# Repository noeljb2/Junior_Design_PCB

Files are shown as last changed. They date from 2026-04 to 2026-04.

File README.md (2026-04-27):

# Bop It — Labubu Edition

An ESP32-S3 based interactive reaction-time game ("Bop It" clone) built into a 3D-printed Labubu figure. Players respond to randomized voice prompts by twisting a knob, shaking the figure, or speaking into the microphone. Difficulty ramps with each round, reaction times shorten, and high scores persist across power cycles.

This is the final design archive for a junior-year ECE 1895 project (University of Pittsburgh, Spring 2026).

---

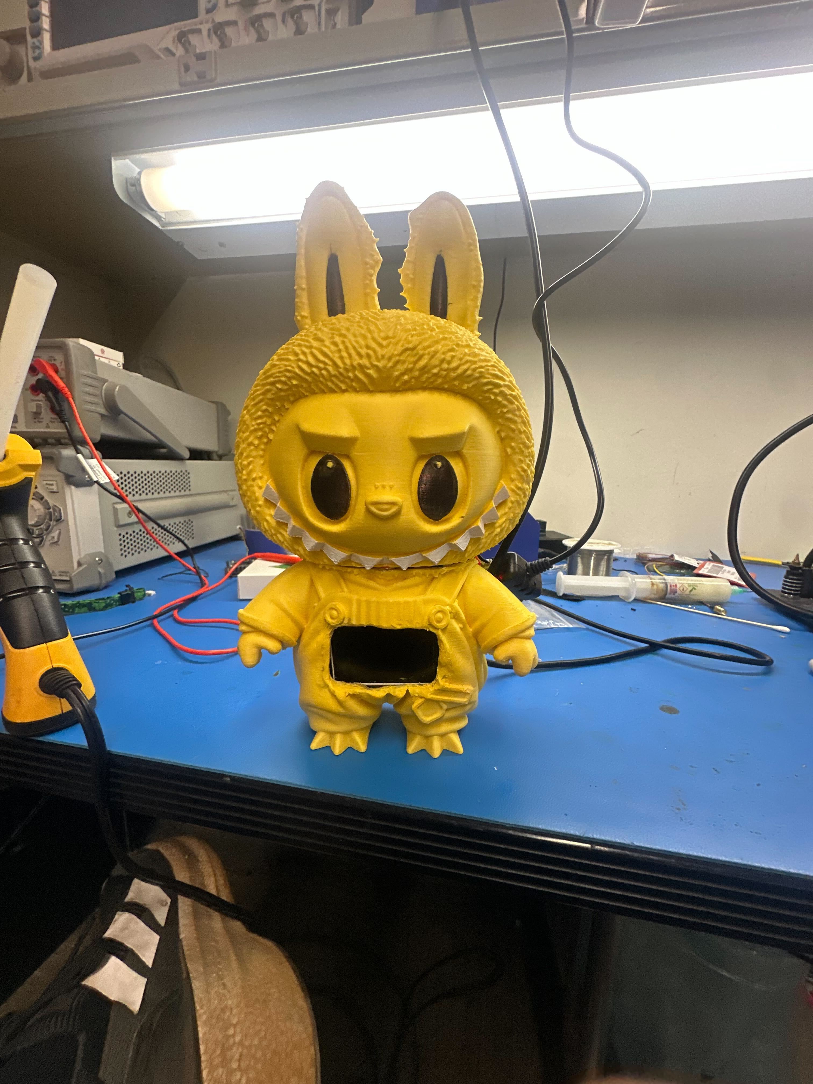
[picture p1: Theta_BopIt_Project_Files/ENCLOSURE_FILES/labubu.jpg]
Front View


## Repository organization

The archive is split by engineering discipline. Each top-level folder is self-contained so that a reviewer (or future builder) can dive into one domain without needing the others.

```
Junior_Design_PCB/
├── README.md                  <- you are here
├── LICENSE
└── Theta_BopIt_Project_Files/
    ├── HARDWARE_DESIGN_FILES/   <- Altium PCB project (schematic, layout, BOM, gerbers, schematic page renders)
    ├── SOFTWARE_FILES/          <- ESP32-S3 firmware (Arduino .ino)
    └── ENCLOSURE_FILES/         <- Bambu Studio 3MF files for 3D-printed parts
```

No external simulation, FEA, or thermal tools were used on this project, so there is no separate `SIMULATION/` folder. Signal-integrity sanity checks were done by hand against the ESP32-S3 datasheet and the peripheral ICs' reference designs.

---

## Hardware

`Theta_BopIt_Project_Files/HARDWARE_DESIGN_FILES/` is an Altium Designer project. The board is a 4-layer PCB built around an ESP32-S3-WROOM-1-N16R8 module.

**Files of interest:**

- `Junior_Design_Bop_It.PrjPcbStructure` — Altium project file. Open this first.
- `LabubuPCB.PcbDoc` — PCB layout (4 layers).
- `MCU.SchDoc` — ESP32-S3 module, decoupling, boot strapping, USB, programming header.
- `USB_POWER.SchDoc` — USB-C input, 5V→3.3V regulation, protection.
- `LCD_AUDIO.SchDoc` — ILI9341 LCD interface and DFPlayer Mini audio interface.
- `Junior_Design_Bop_It.BomDoc` — bill of materials.
- `Gerber_Outputs_Labubu.zip` — fabrication-ready Gerbers (sent to JLCPCB).
- `Junior_Design_Bop_It.PDF` — full printed schematic (all sheets) for review without Altium.

### Schematic

The four sheets of the schematic are rendered below as PNGs so they can be reviewed directly on GitHub without opening the PDF.

**Sheet 1 — MCU + TOP LEVEL**

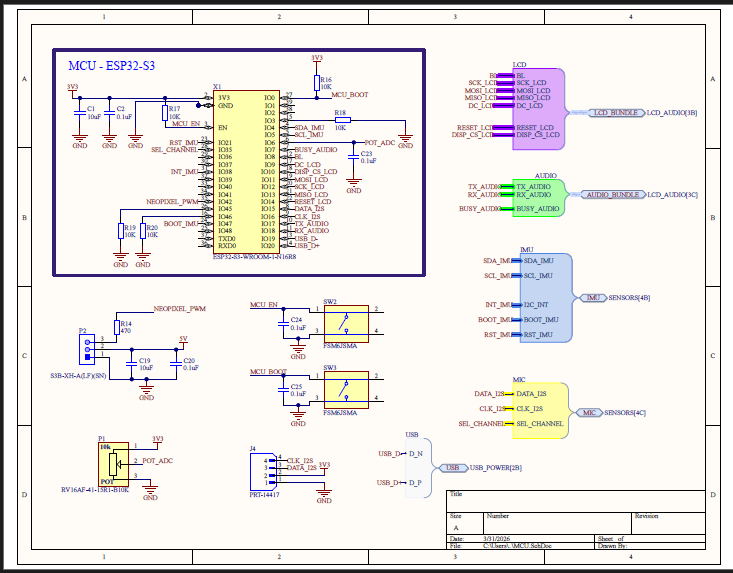
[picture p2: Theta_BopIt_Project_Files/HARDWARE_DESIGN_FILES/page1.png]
Schematic page 1


**Sheet 2 — IMU + MIC**

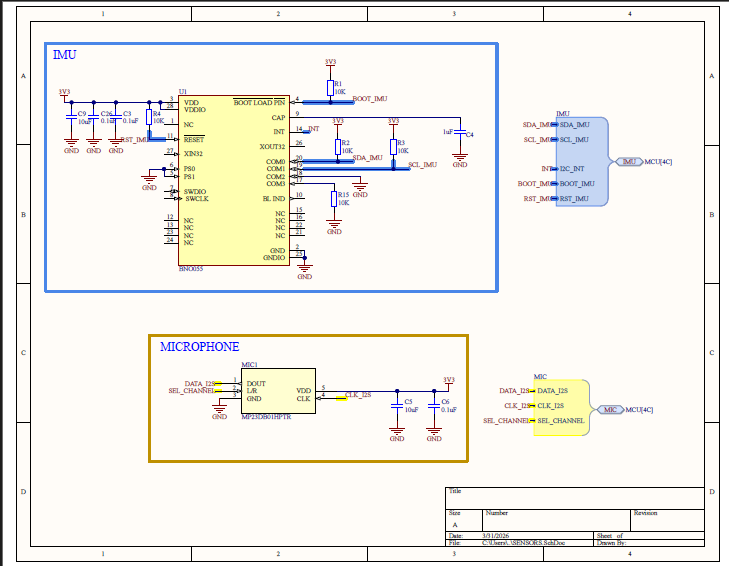
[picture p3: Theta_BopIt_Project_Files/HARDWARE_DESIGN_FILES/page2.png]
Schematic page 2


**Sheet 3 — LCD and audio**

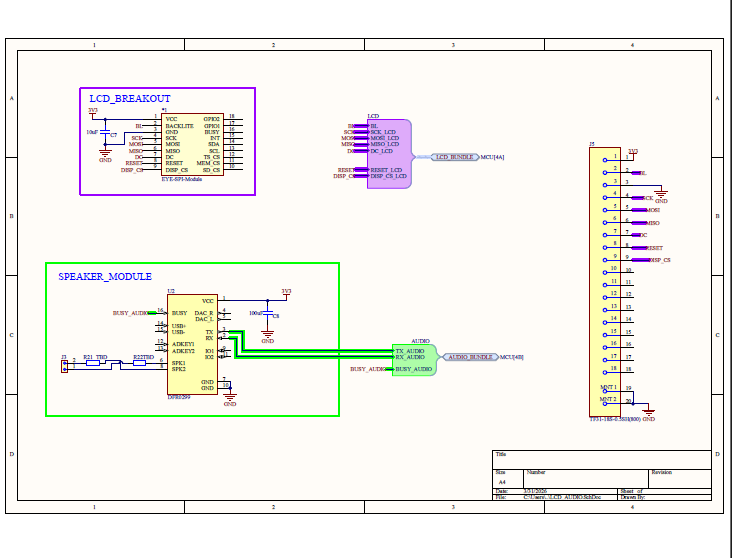
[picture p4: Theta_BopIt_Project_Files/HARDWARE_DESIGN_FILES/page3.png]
Schematic page 3


**Sheet 4 — USB and power**

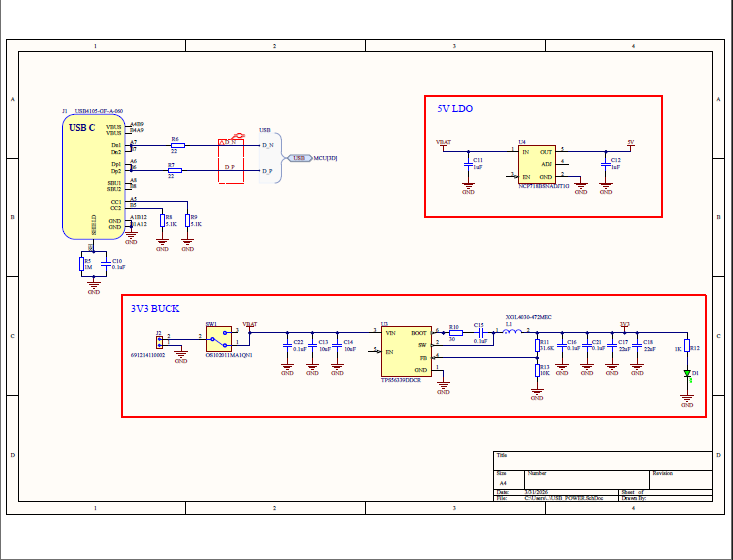
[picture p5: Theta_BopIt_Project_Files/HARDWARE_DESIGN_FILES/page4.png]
Schematic page 4


For the full PDF, see [`Junior_Design_Bop_It.PDF`](Theta_BopIt_Project_Files/HARDWARE_DESIGN_FILES/Junior_Design_Bop_It.PDF).

### Major peripherals

| Function | Part | Interface |
|---|---|---|
| MCU | ESP32-S3-WROOM-1-N16R8 | — |
| Display | ILI9341 2.4" TFT | SPI |
| IMU (shake detect) | BNO055 | I²C |
| Microphone | PDM MEMS | I²S |
| User input | Rotary potentiometer | ADC |
| Audio playback | DFPlayer Mini + speaker | UART |

The `__Previews/`, `Project Outputs for Junior_Design_Bop_It/`, `History/`, and `Project Logs for Junior_Design_Bop_It/` folders are Altium-generated and can be ignored unless debugging the design history.

---

## Software

`Theta_BopIt_Project_Files/SOFTWARE_FILES/` contains the firmware as a single Arduino sketch.

**Files of interest:**

- `labubu_bopit_1.ino` — full firmware (state machine, peripheral drivers, scoring, audio cues).

**Build environment:**

- Arduino IDE 2.x with the ESP32 board package (espressif/arduino-esp32).
- Board target: `ESP32S3 Dev Module`, Flash 16 MB, PSRAM `OPI PSRAM`.
- Required libraries: `Adafruit_GFX`, `Adafruit_ILI9341`, `Adafruit_BNO055`, `DFRobotDFPlayerMini`, `ESP_I2S` (built into the ESP32 core).

To flash: open the `.ino`, select the board settings above, plug in the unit over USB-C, and upload. The device boots into a splash screen on the LCD and waits for the start prompt.

---

## Enclosure

`Theta_BopIt_Project_Files/ENCLOSURE_FILES/` contains all 3D-printable parts as Bambu Studio `.3mf` project files. Print on any FDM printer; PLA at 0.2 mm layer height was used for the demo unit.

**Files of interest:**

- `labubu_scaled_hollow.3mf` — the main Labubu figure body (scaled up and hollowed to fit the PCB stack and speaker).
- `PotOutsidePlate_Actobotics_v04.3mf` — outer faceplate that the potentiometer mounts through.
- `PotInsidePlate_Actobotics_v04.3mf` — inner retainer that captures the pot against the outer plate.
- `lcd-bracket.3mf` — bracket that holds the ILI9341 module behind its cutout.
- `Knob-designv2.3mf` — knurled knob that presses onto the potentiometer shaft.

The Actobotics-named parts mount to a 1.5" Actobotics channel that runs through the figure as the internal chassis.

---

## Reproducing the build

If you want to rebuild this project from the archive:

1. **PCB** — open the Altium project in `HARDWARE_DESIGN_FILES/`, regenerate Gerbers (or use the included zip), and order from any 4-layer fab. Stuff per the BOM. Most parts are 0402/0603 hand-solderable; the ESP32-S3 module and DFPlayer are through-hole-friendly.
2. **Print** — slice each `.3mf` in `ENCLOSURE_FILES/` and print in PLA. The Labubu body is the long print (~14 hours).
3. **Flash** — open `SOFTWARE_FILES/labubu_bopit_1.ino` in the Arduino IDE, install the libraries listed above, and upload to the assembled board.
4. **Assemble** — mount the PCB to the Actobotics channel, fit the LCD into its bracket, press the knob onto the pot through the faceplates, drop the assembly into the Labubu shell, and screw the head back on.

---

## Notes

- The full git history of the hardware project lives in `HARDWARE_DESIGN_FILES/.git/` if you want to see how the schematic and layout evolved.
- The `CAMtastic1` file under `HARDWARE_DESIGN_FILES/` is an Altium CAM check of the Gerbers; not needed for fabrication, but useful for verifying drill alignment.
- This was a class project. The board has not been through EMC testing and should not be treated as a production design.

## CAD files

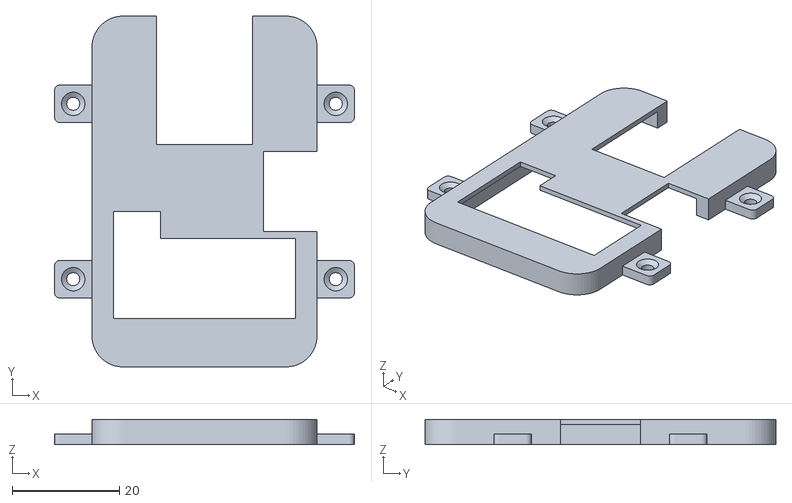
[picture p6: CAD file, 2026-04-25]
Theta_BopIt_Project_Files/ENCLOSURE_FILES/lcd-bracket.stl
56.1 x 65.6 x 4.75

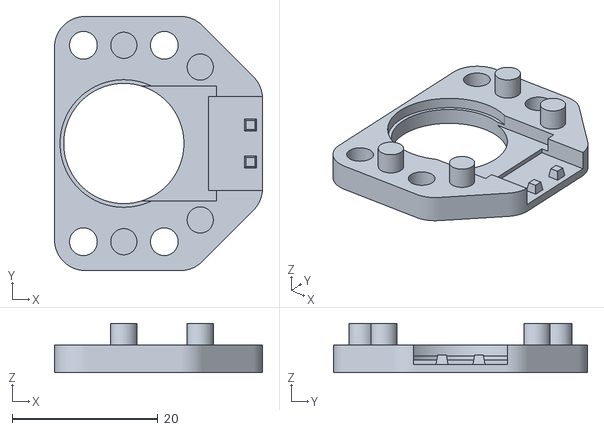
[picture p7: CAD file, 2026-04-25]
Theta_BopIt_Project_Files/ENCLOSURE_FILES/PotOutsidePlate_Actobotics_v04.STL
28.6 x 34.9 x 6.79

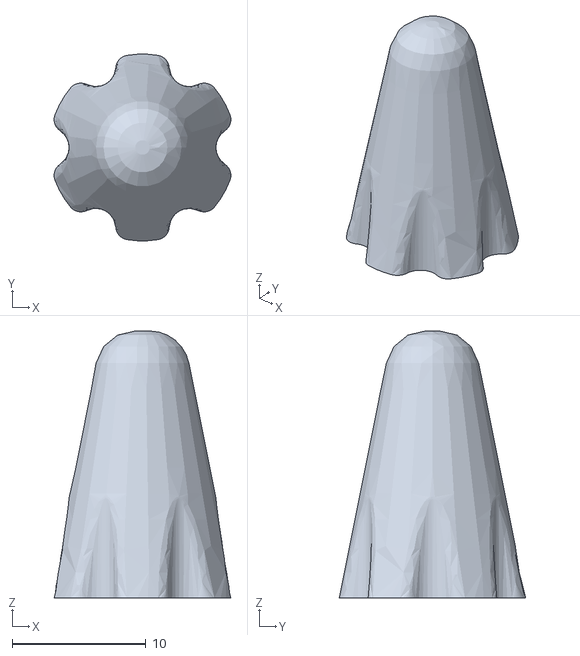
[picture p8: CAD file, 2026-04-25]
Theta_BopIt_Project_Files/ENCLOSURE_FILES/Knob-designv2.stl
13.2 x 14.0 x 20.0

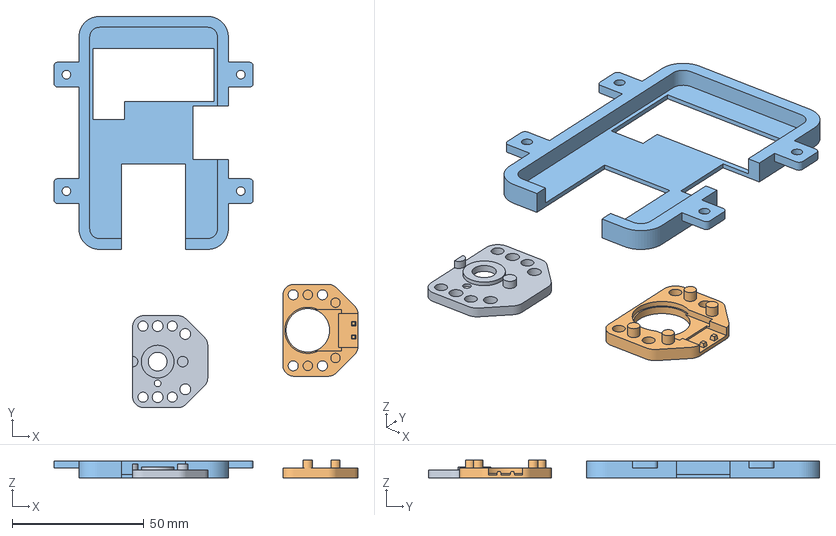
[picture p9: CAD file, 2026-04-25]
Theta_BopIt_Project_Files/ENCLOSURE_FILES/PotInsidePlate_Actobotics_v04.3mf
115.5 x 148.6 x 6.79 mm
PotInsidePlate_Actobotics_v04.STL
PotOutsidePlate_Actobotics_v04.STL
lcd-bracket.stl

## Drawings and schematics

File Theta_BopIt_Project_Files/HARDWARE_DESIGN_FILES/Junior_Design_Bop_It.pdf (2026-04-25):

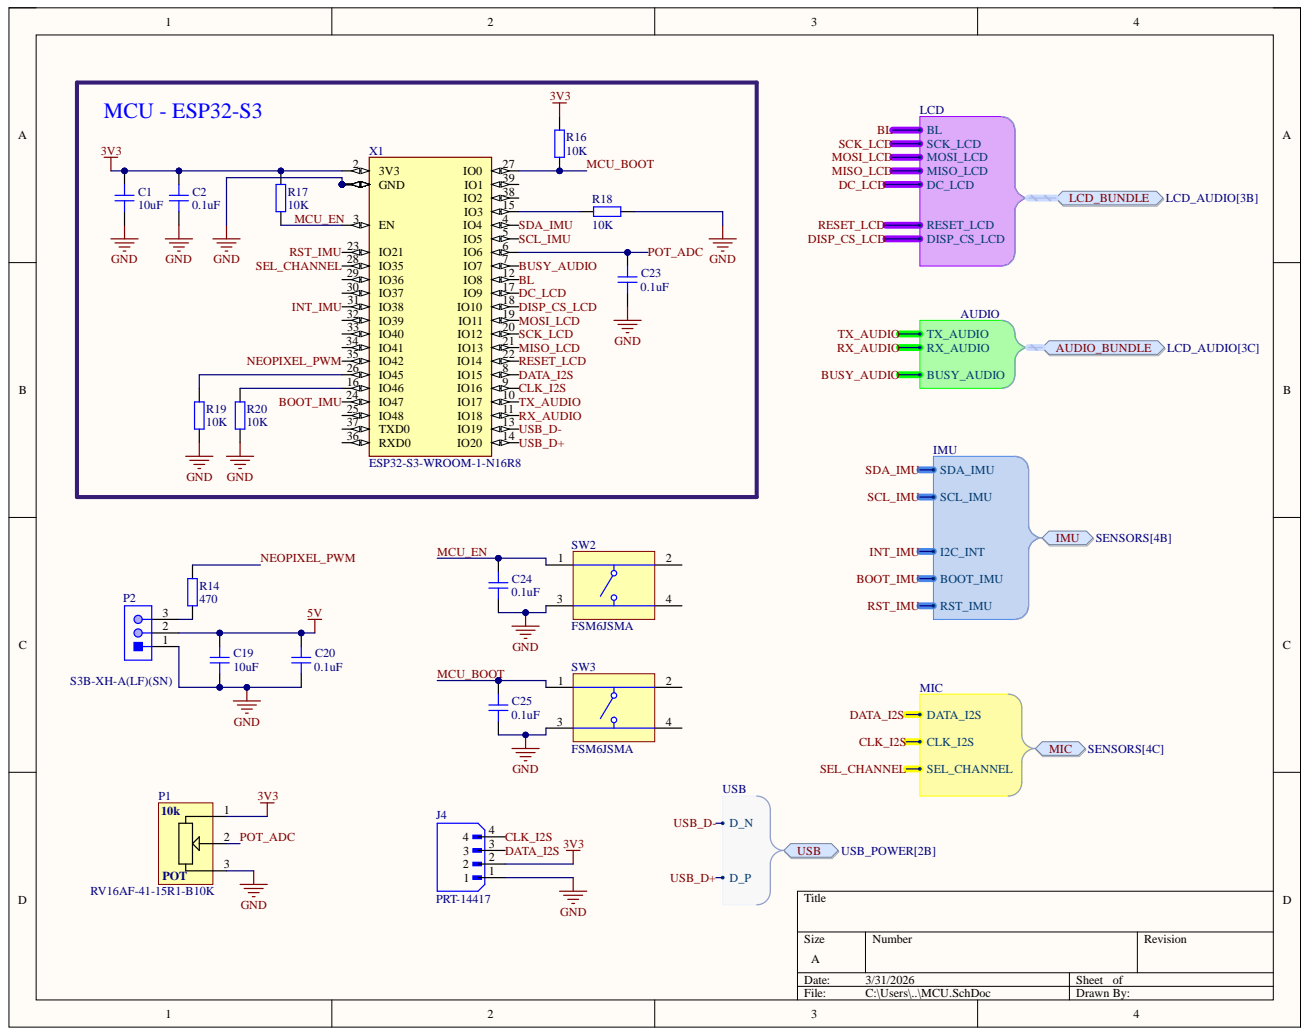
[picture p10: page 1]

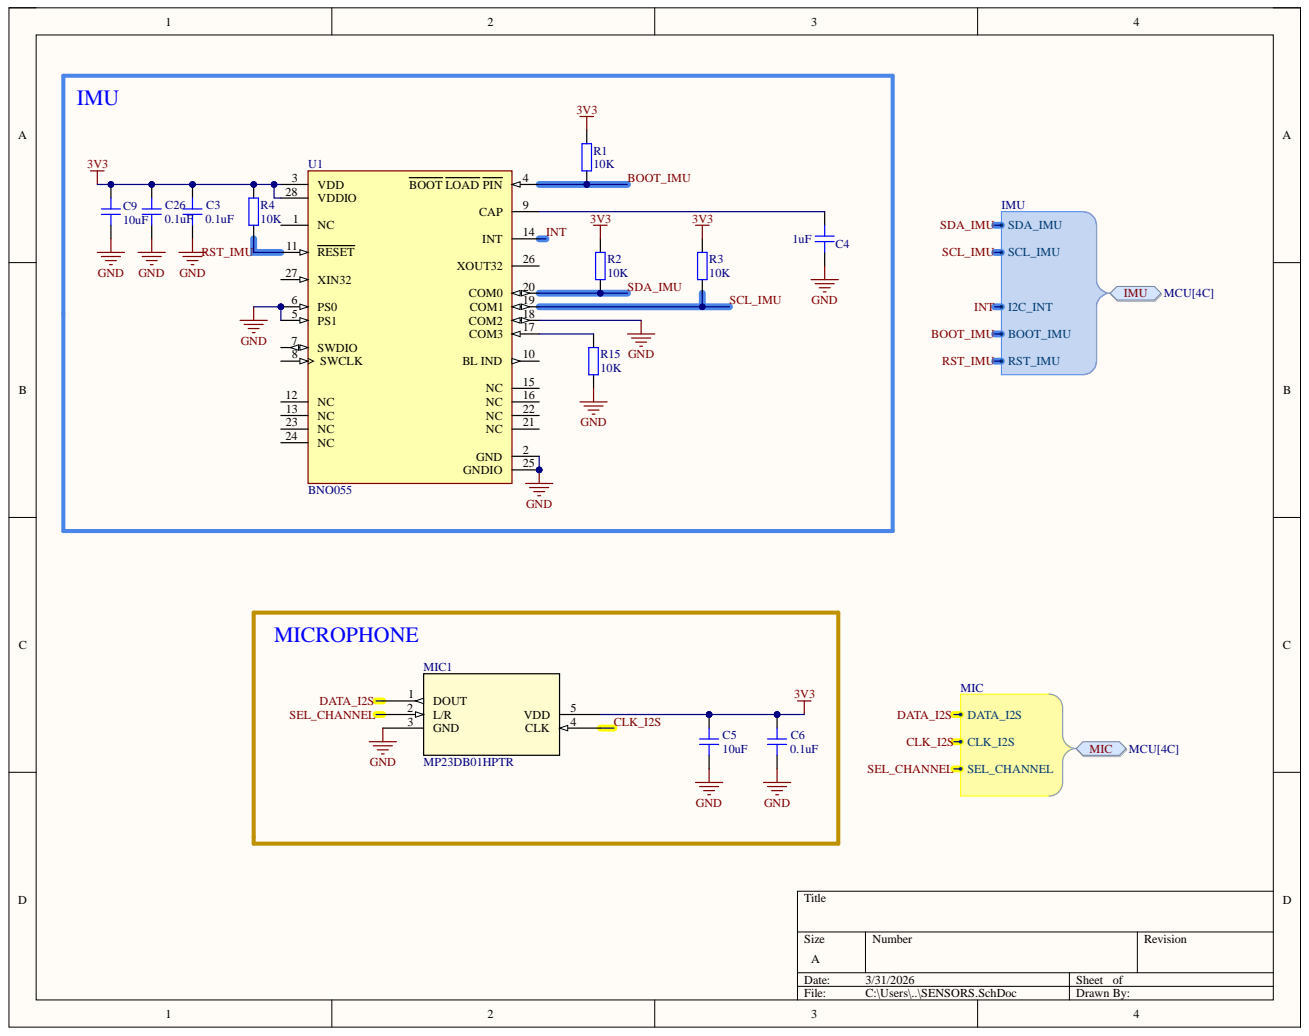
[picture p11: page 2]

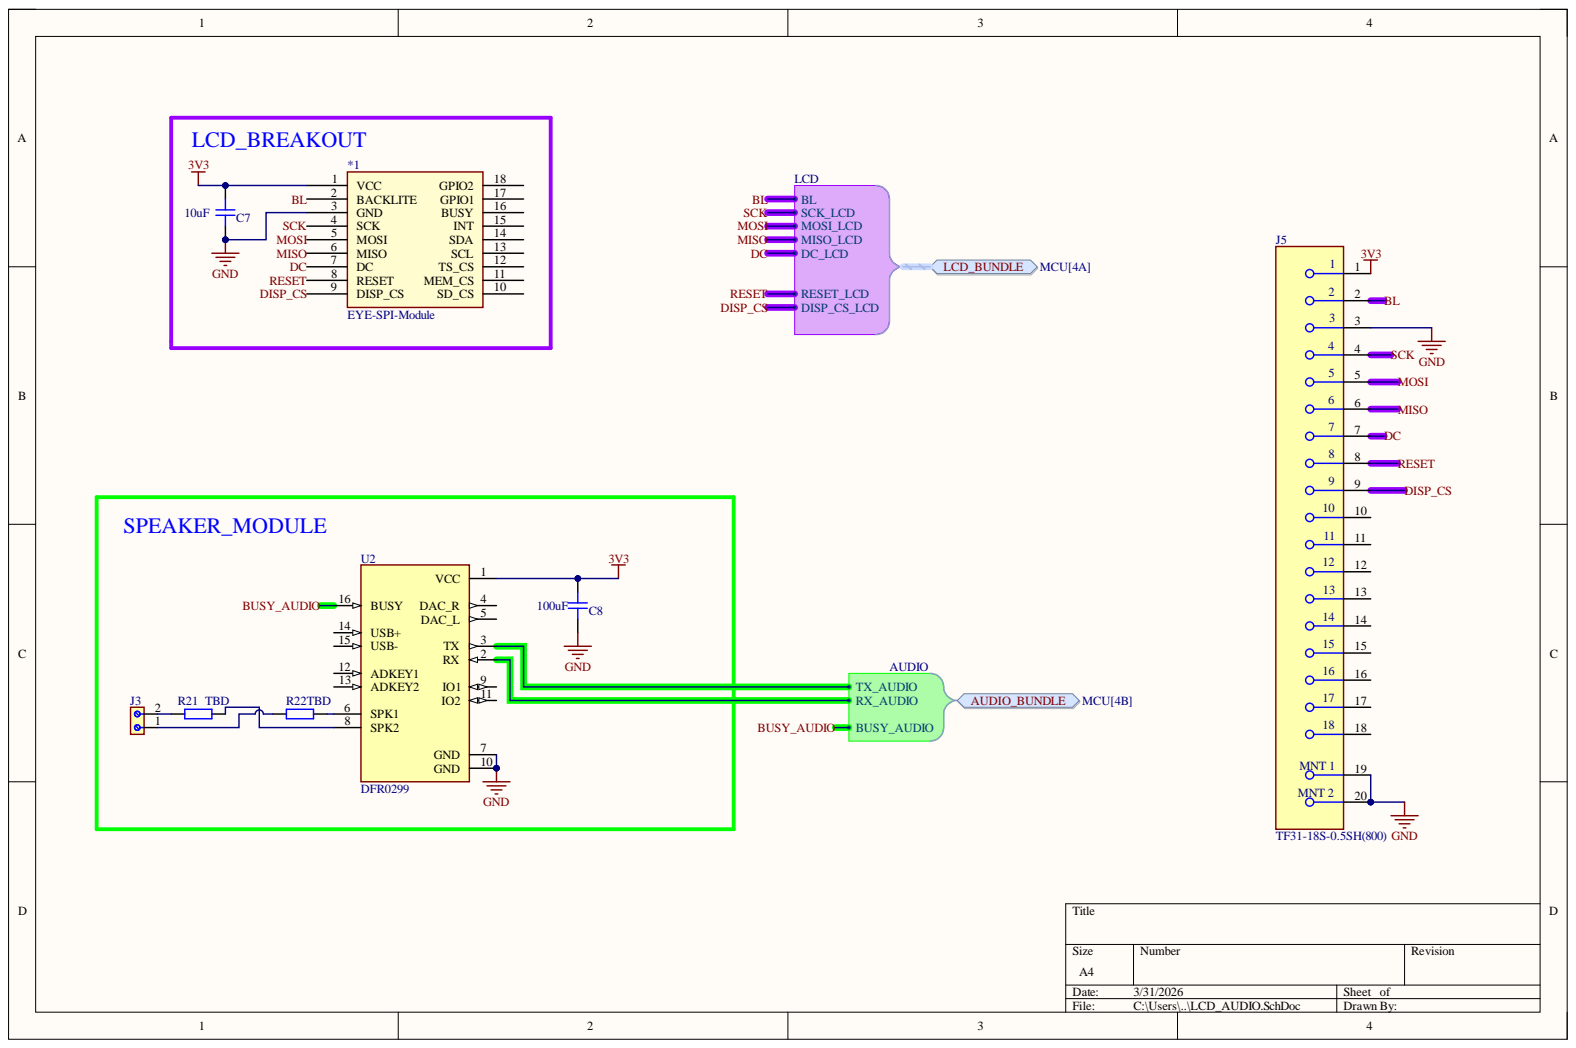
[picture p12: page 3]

Size A4 | Number | Revision

Date: 3/31/2026 | Sheet of
File: C:\Users\..\LCD_AUDIO.SchDoc | Drawn By:

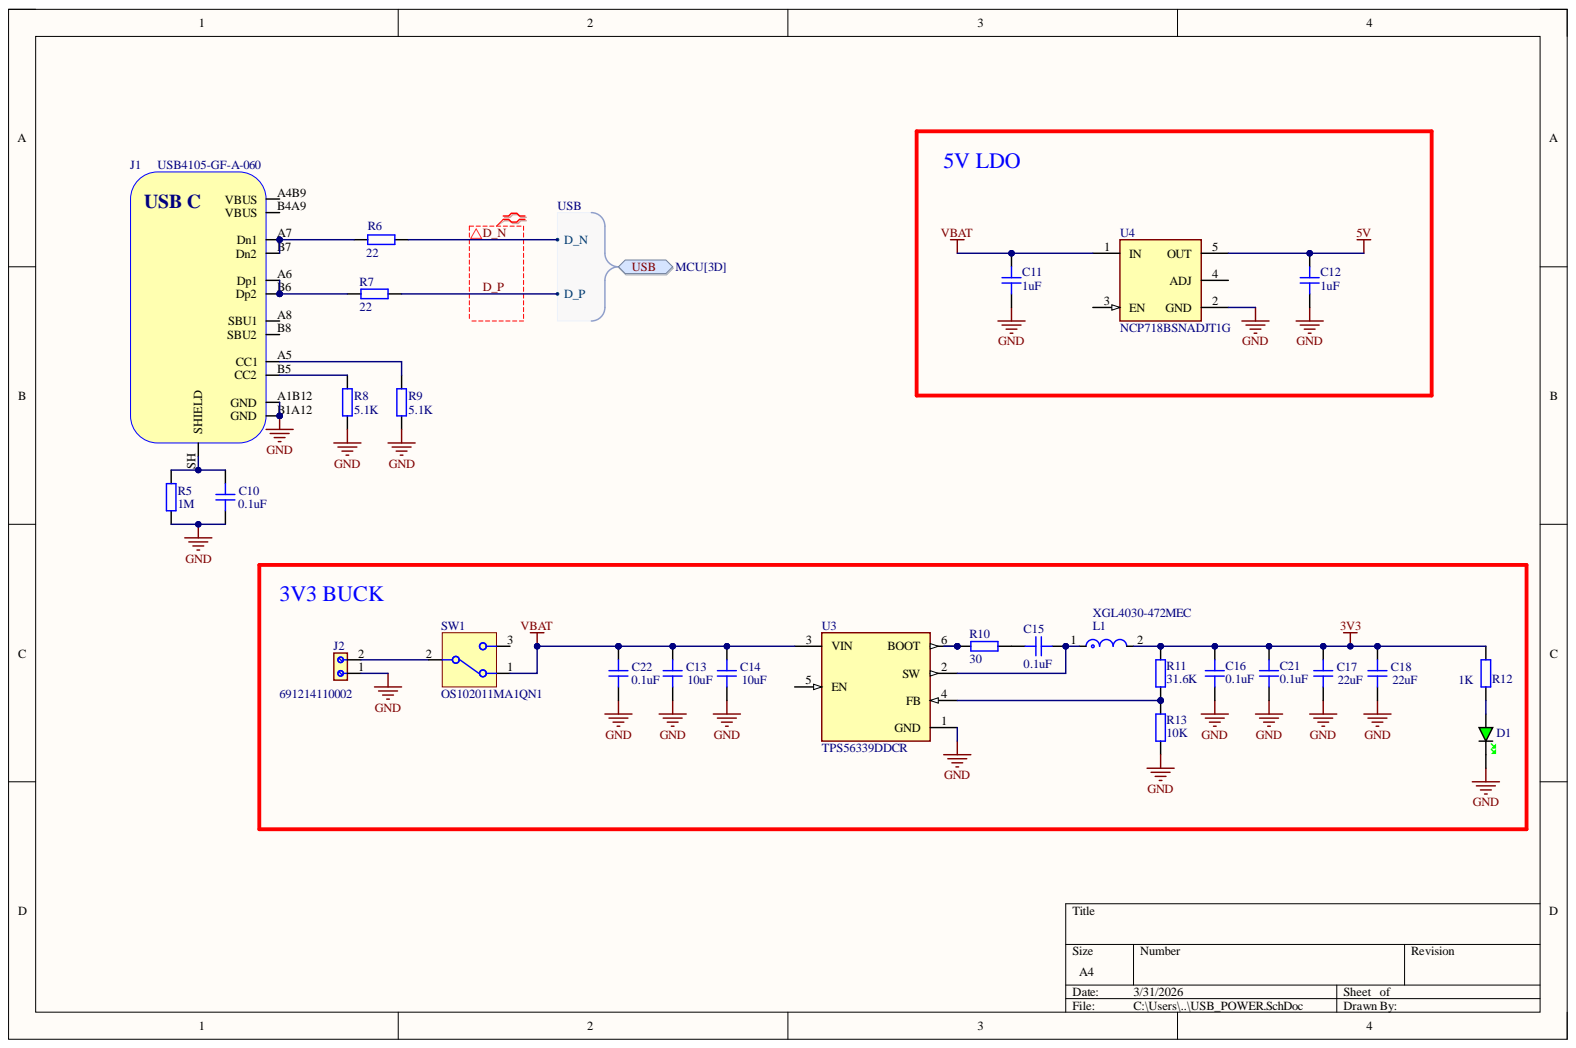
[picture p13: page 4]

Size A4 | Number | Revision

Date: 3/31/2026 | Sheet of
File: C:\Users\..\USB_POWER.SchDoc | Drawn By:

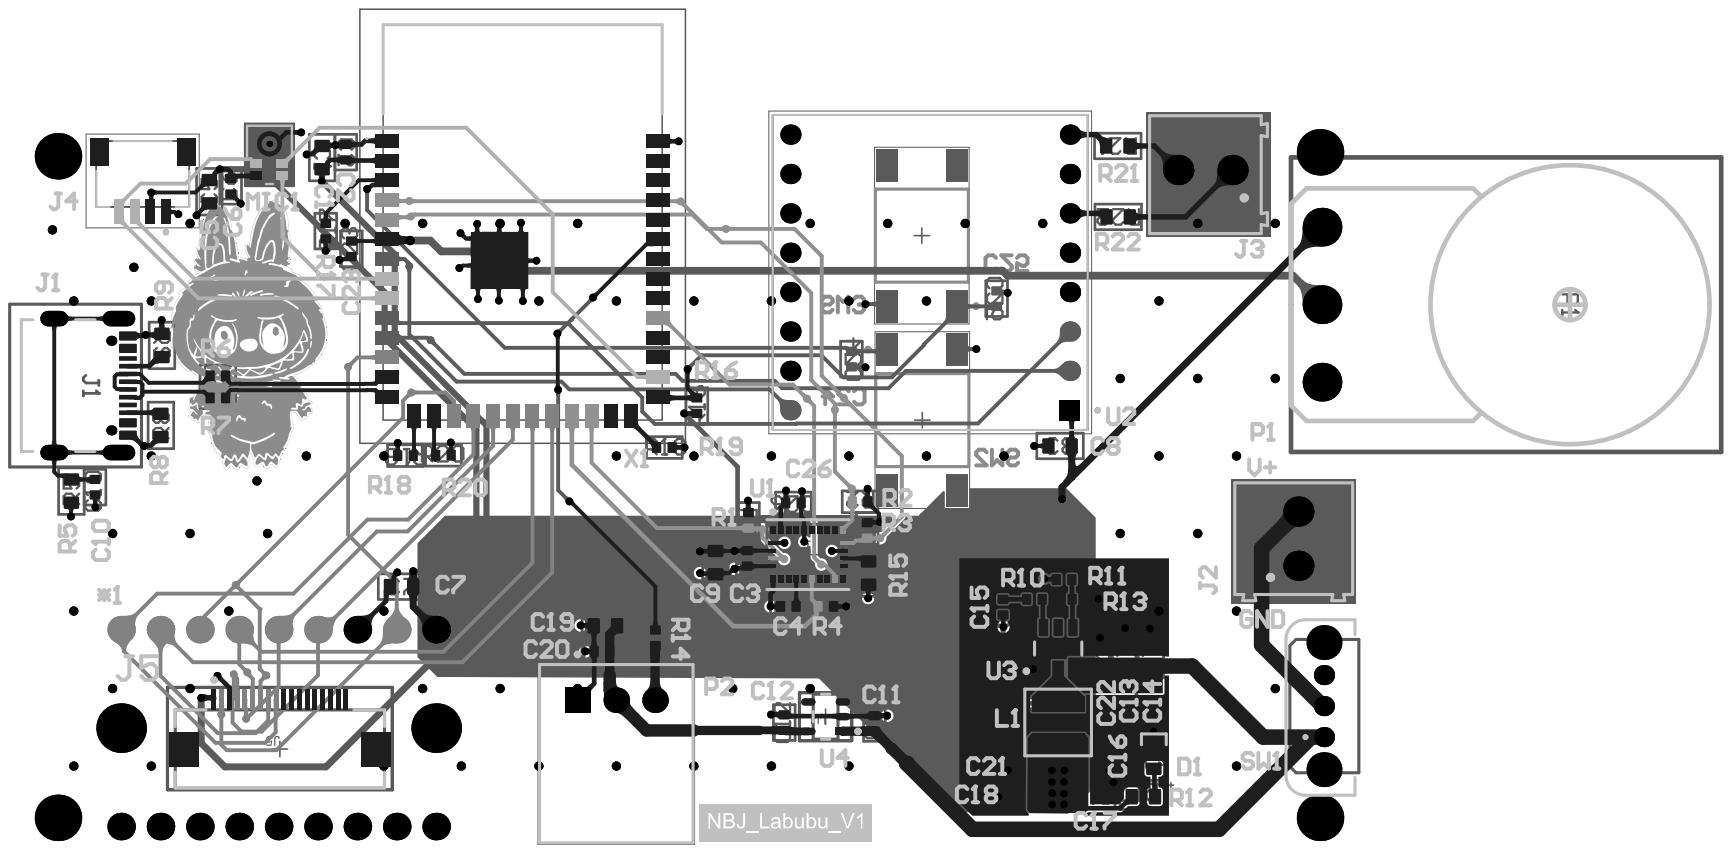
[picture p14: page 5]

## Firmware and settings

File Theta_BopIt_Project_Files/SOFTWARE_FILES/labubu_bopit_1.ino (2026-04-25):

#include <Arduino.h>
#include <SPI.h>
#include <Adafruit_GFX.h>
#include <Adafruit_ILI9341.h>
#include <Wire.h>
#include <Adafruit_BNO055.h>
#include "ESP_I2S.h"
#include <math.h>

// ─── Pin Definitions (verified) ──────────────────────────────────────────────
#define PIN_SDA         4
#define PIN_SCL         5
#define PIN_POT         6
#define PIN_BUSY_AUDIO  7
#define PIN_BL          8
#define PIN_DC_LCD      9
#define PIN_DISP_CS     10
#define PIN_MOSI        11
#define PIN_SCK         12
#define PIN_MISO        13
#define PIN_RESET_LCD   14
#define PIN_DATA_I2S    15
#define PIN_CLK_I2S     16
#define PIN_TX_AUDIO    18
#define PIN_RX_AUDIO    17
#define PIN_INT_IMU     38
#define PIN_SEL_CH      39
#define PIN_BOOT_IMU    40
#define PIN_RST_IMU     21

// ─── Hardware Config ─────────────────────────────────────────────────────────
#define SAMPLE_LEN          256

// ─── Game Tuning ─────────────────────────────────────────────────────────────
#define SCREAM_THRESH       800.0f
#define POT_TWIST_THRESH    300
#define INPUT_TIMEOUT_MS    4000
#define MIN_TIMEOUT_MS      500        // floor per spec
#define TIMEOUT_DECAY_PCT   12          // reduce timeout by 12% every SPEEDUP_INTERVAL actions
#define SPEEDUP_INTERVAL    5
#define POINTS_PER_SUCCESS  5           // per spec
#define WIN_SCORE           100         // per spec — game ends at 100

// ─── Wrong-Action Detection ──────────────────────────────────────────────────
// When a round is active for action X, we also monitor the OTHER inputs to
// detect the player performing the wrong action → instant fail.
// Mic is intentionally EXCLUDED from fail detection (or uses a much higher
// threshold) to avoid false triggers from ambient noise, the speaker itself
// playing a prompt, heavy breathing, etc.
#define WRONG_POT_THRESH    500     // larger than success threshold — must be a clear twist
#define WRONG_TILT_DEG      30.0f   // larger than cradle threshold — must be a clear tilt
#define WRONG_SCREAM_ENABLED 0      // 0 = never fail on loud noise, 1 = fail only on insane volume
#define WRONG_SCREAM_THRESH 1800.0f // only used if WRONG_SCREAM_ENABLED = 1 (much higher than success)

// ─── Audio Timing ────────────────────────────────────────────────────────────
// DFPlayer BUSY pin is active-LOW while playing. We block until it's HIGH
// (idle) or we hit the timeout below. Prevents the game from clipping a
// prompt or sitting forever on a dead DFPlayer.
#define AUDIO_WAIT_MAX_MS   3500        // hard ceiling for any single clip
#define AUDIO_START_MS      150         // give DFPlayer time to assert BUSY

// ─── Cradle (Tilt) Tuning ────────────────────────────────────────────────────
// Uses roll angle (gravity-referenced, no drift). Player must rock the device
// from one side to the other — like cradling a baby. Two side-changes = win.
#define CRADLE_TILT_DEG     22.0f   // how far you must tilt to register one side
#define CRADLE_HYST_DEG     8.0f    // must return below this before the other side counts
#define CRADLE_REQUIRED     2       // number of side-changes needed (left↔right)
#define CRADLE_SETTLE_DEG   30.0f   // if starting tilt > this, ask user to level it first
#define CRADLE_FRAME_MS     33      // ~30 fps redraw cap

// ─── Colors ──────────────────────────────────────────────────────────────────
#define COL_BG          0x0000
#define COL_TITLE       0xFFE0
#define COL_ACTION      0xF800
#define COL_SCORE       0x07FF
#define COL_SUCCESS     0x07E0
#define COL_FAIL        0xF800
#define COL_BAR         0x07E0
#define COL_BAR_BG      0x4208
#define COL_CRADLE      0xFD20   // orange
#define COL_LIT         0x07E0   // green when a side is hit
#define COL_WHITE       0xFFFF
#define COL_DIMWHITE    0x8410

// ─── DFPlayer Sound Bank ─────────────────────────────────────────────────────
// Uses DFPlayer command 0x0F (play file by name in folder). File numbers
// below correspond DIRECTLY to the 3-digit filename prefix on the SD card —
// file write order is IRRELEVANT with this command.
//
// Confirmed working via diag sketch: folder mode reads filenames correctly.
//
// Required SD layout (files 000-014, exactly as originally recorded):
//   /01/000.mp3  "Listen to exactly what I say..."       ← start
//   /01/001.mp3  "Twist my ear, or else!"                ← twist prompt
//   /01/002.mp3  "Tilt me, tilt me, tilt me!"            ← tilt prompt
//   /01/003.mp3  "Scream at me, you won't!"              ← scream prompt
//   /01/004.mp3  "Ha ha ha, you lost, LOSER!!!"          ┐
//   /01/005.mp3  "Too slow! Pathetic!"                   │ fail bank
//   /01/006.mp3  "Game over! I win, obviously!"          ┘
//   /01/007.mp3  "Too easy. Boring!"                     ┐
//   /01/008.mp3  "Faster! Keep up!"                      │ level-up bank
//   /01/009.mp3  "Finally a challenge. Maybe."           ┘
//   /01/010.mp3  "Fine. Next!"                           ┐
//   /01/011.mp3  "Lucky. Don't get cocky!"               │ success bank
//   /01/012.mp3  "Hmph. Again!"                          ┘
//   /01/013.mp3  "Good job, human..."                    ┐ win bank
//   /01/014.mp3  "New high score!"                       ┘
//
// Folder must be named exactly "01" (2 digits). Filenames must start with
// exactly 3 digits. Extensions .mp3 or .wav both work.

#define SFX_START           0   // file 000
#define SFX_PROMPT_TWIST    1   // file 001
#define SFX_PROMPT_TILT     2   // file 002
#define SFX_PROMPT_SCREAM   3   // file 003

const uint8_t SFX_FAIL_BANK[]    = { 4, 5, 6 };
const uint8_t SFX_LEVELUP_BANK[] = { 7, 8, 9 };
const uint8_t SFX_SUCCESS_BANK[] = { 10, 11, 12 };
const uint8_t SFX_WIN_BANK[]     = { 13, 14 };

#define SFX_FAIL_COUNT      (sizeof(SFX_FAIL_BANK))
#define SFX_LEVELUP_COUNT   (sizeof(SFX_LEVELUP_BANK))
#define SFX_SUCCESS_COUNT   (sizeof(SFX_SUCCESS_BANK))
#define SFX_WIN_COUNT       (sizeof(SFX_WIN_BANK))

// ─── Action Enum (declared early so helpers can reference it) ────────────────
enum Action { ACT_TWIST, ACT_SCREAM, ACT_CRADLE, ACT_COUNT };
const char* actionNames[] = { "TWIST IT!", "SCREAM!", "TILT IT!" };

// ─── Objects ─────────────────────────────────────────────────────────────────
Adafruit_ILI9341    tft = Adafruit_ILI9341(&SPI, PIN_DC_LCD, PIN_DISP_CS, PIN_RESET_LCD);
Adafruit_BNO055     bno(55, 0x28, &Wire);
I2SClass            i2s;
HardwareSerial      dfSerial(1);

// ─── Globals ─────────────────────────────────────────────────────────────────
int     score           = 0;
int     highScore       = 0;
int     timeoutMs       = INPUT_TIMEOUT_MS;
int     potBaseline     = 0;
int     roundCount      = 0;
int     twistCount      = 0;
int     screamCount     = 0;
int     cradleCount     = 0;
float   fastestReaction = 99999;
float   totalReaction   = 0;
bool    gameRunning     = false;
bool    dfPlayerOk      = false;
bool    imuOk           = false;

int16_t micBuf[SAMPLE_LEN];

// ─── Forward Declarations ────────────────────────────────────────────────────
void    showAction(Action a);
void    showSuccess(float reactionMs);
void    showGameOver();
void    showTitle();
void    showCountdown();
bool    waitForAction(Action a, int timeout, float &reactionMs, bool &wrongAction);
Action  pickAction();
int     promptTrackFor(Action a);
void    startGame();
void    gameLoop();
void    gameOver(bool won);
void    playTrack(int t);
void    playAndWait(int track);
void    playRandomAndWait(const uint8_t* bank, size_t n);
void    waitForAudioToFinish();
void    centerText(const char* txt, int y, int size, uint16_t color);
void    drawProgressBar(int x, int y, int w, int h, float pct, uint16_t fg, uint16_t bg);
float   readMicRMS();
float   readRollDeg();
void    drawCradleScene(float roll, int sidesHit, bool leftLit, bool rightLit,
                        float elapsed, int timeout, bool dirty);
void    dfPlayTrack(uint16_t track);
void    dfSetVolume(uint8_t vol);
bool    detectWrongAction(Action expected, int wrongPotBase, float wrongTiltBase);

// ─── DFPlayer Raw Commands ───────────────────────────────────────────────────
// IMPORTANT: Uses command 0x0F (play specific file in folder) — NOT 0x03
// (play by index). With 0x0F, DFPlayer reads the 3-digit prefix from the
// filename (e.g. /01/005.mp3 → file 5). Order on the SD card doesn't matter.
//
// File layout required on SD:
//   /01/001.mp3, /01/002.mp3, ... /01/015.mp3
//   (Folder name: 2 digits. File prefix: 3 digits. Extra text after is OK.)
//
// The DFPlayer CHECKSUM field was omitted in the original 0x03 version — we
// compute it properly here because some clone modules reject unchecksummed
// 0x0F commands even though they accepted 0x03 silently.

static uint16_t dfChecksum(const uint8_t* frame /* 6 bytes from 0xFF to param_lo */) {
    uint16_t sum = 0;
    for (int i = 0; i < 6; i++) sum += frame[i];
    return -sum;  // two's complement per DFPlayer spec
}

// Play file NNN in folder FF (e.g. dfPlayFile(1, 5) → /01/005.mp3).
void dfPlayFile(uint8_t folder, uint8_t fileNum) {
    uint8_t body[6] = { 0xFF, 0x06, 0x0F, 0x00, folder, fileNum };
    uint16_t sum = dfChecksum(body);
    uint8_t cmd[10] = {
        0x7E, 0xFF, 0x06, 0x0F, 0x00, folder, fileNum,
        (uint8_t)(sum >> 8), (uint8_t)(sum & 0xFF), 0xEF
    };
    dfSerial.write(cmd, sizeof(cmd));
}

// Wrapper used by the rest of the game: all files live in /01/.
void dfPlayTrack(uint16_t track) {
    dfPlayFile(1, (uint8_t)track);
}

void dfSetVolume(uint8_t vol) {
    uint8_t body[6] = { 0xFF, 0x06, 0x06, 0x00, 0x00, vol };
    uint16_t sum = dfChecksum(body);
    uint8_t cmd[10] = {
        0x7E, 0xFF, 0x06, 0x06, 0x00, 0x00, vol,
        (uint8_t)(sum >> 8), (uint8_t)(sum & 0xFF), 0xEF
    };
    dfSerial.write(cmd, sizeof(cmd));
}

void playTrack(int t) {
    if (dfPlayerOk) {
        dfPlayTrack(t);
        delay(80);
    }
}

// ─── Wait for DFPlayer BUSY pin to go idle (HIGH) ────────────────────────────
void waitForAudioToFinish() {
    if (!dfPlayerOk) return;

    unsigned long t0 = millis();

    while ((millis() - t0) < AUDIO_START_MS) {
        if (digitalRead(PIN_BUSY_AUDIO) == LOW) break;
        delay(5);
    }

    unsigned long t1 = millis();
    while ((millis() - t1) < AUDIO_WAIT_MAX_MS) {
        if (digitalRead(PIN_BUSY_AUDIO) == HIGH) {
            unsigned long confirm = millis();
            bool stable = true;
            while ((millis() - confirm) < 30) {
                if (digitalRead(PIN_BUSY_AUDIO) == LOW) { stable = false; break; }
                delay(2);
            }
            if (stable) return;
        }
        delay(5);
    }
}

void playAndWait(int track) {
    if (!dfPlayerOk) return;
    dfPlayTrack(track);
    waitForAudioToFinish();
}

void playRandomAndWait(const uint8_t* bank, size_t n) {
    if (!dfPlayerOk || n == 0) return;
    uint8_t track = bank[random(0, (long)n)];
    playAndWait(track);
}

// ─── IMU Helper ──────────────────────────────────────────────────────────────
float readRollDeg() {
    if (!imuOk) return 0.0f;
    imu::Vector<3> euler = bno.getVector(Adafruit_BNO055::VECTOR_EULER);
    return (float)euler.y();
}

// ─── Mic RMS ─────────────────────────────────────────────────────────────────
float readMicRMS() {
    size_t bytesRead = i2s.readBytes((char*)micBuf, sizeof(micBuf));
    int count = bytesRead / sizeof(int16_t);
    if (count == 0) return 0.0f;

    float sumSq = 0;
    for (int i = 0; i < count; i++) {
        float s = (float)micBuf[i];
        sumSq += s * s;
    }
    return sqrtf(sumSq / (float)count);
}

// ─── Wrong-Action Detector ───────────────────────────────────────────────────
// Called each frame of waitForAction. Returns true if the player is clearly
// doing something OTHER than the expected action.
//
//   expected      - the action the player was asked to perform
//   wrongPotBase  - pot reading captured at round start (for detecting a
//                   twist when the expected action isn't twist)
//   wrongTiltBase - roll angle captured at round start (for detecting a
//                   tilt when the expected action isn't tilt)
//
// Mic is deliberately leaky: we don't fail on loud noise by default because
// ambient sound and speaker prompts can false-trigger. Set
// WRONG_SCREAM_ENABLED=1 if you want extra-loud noise to count as a fail.
bool detectWrongAction(Action expected, int wrongPotBase, float wrongTiltBase) {
    // Check unintended POT movement
    if (expected != ACT_TWIST) {
        int current = analogRead(PIN_POT);
        if (abs(current - wrongPotBase) > WRONG_POT_THRESH) return true;
    }

    // Check unintended TILT movement (roll axis)
    if (expected != ACT_CRADLE && imuOk) {
        float roll = readRollDeg();
        if (fabsf(roll - wrongTiltBase) > WRONG_TILT_DEG) return true;
    }

    // Check unintended SCREAM (optional — off by default)
#if WRONG_SCREAM_ENABLED
    if (expected != ACT_SCREAM) {
        float rms = readMicRMS();
        if (rms > WRONG_SCREAM_THRESH) return true;
    }
#endif

    return false;
}

// ─── Draw Helpers ────────────────────────────────────────────────────────────
void drawProgressBar(int x, int y, int w, int h, float pct, uint16_t fg, uint16_t bg) {
    if (pct < 0) pct = 0;
    if (pct > 1) pct = 1;
    int filled = (int)(w * pct);
    if (filled > 0) tft.fillRect(x, y, filled, h, fg);
    if (filled < w) tft.fillRect(x + filled, y, w - filled, h, bg);
}

void centerText(const char* txt, int y, int size, uint16_t color) {
    tft.setTextSize(size);
    tft.setTextColor(color);
    int16_t x1, y1;
    uint16_t w, h;
    tft.getTextBounds(txt, 0, 0, &x1, &y1, &w, &h);
    tft.setCursor((320 - w) / 2, y);
    tft.print(txt);
}

// ─── Screens ─────────────────────────────────────────────────────────────────
void showTitle() {
    tft.fillScreen(COL_BG);
    centerText("LABUBU", 30, 4, COL_TITLE);
    centerText("BOP IT!", 80, 4, COL_ACTION);

    tft.setTextSize(2);
    tft.setTextColor(COL_DIMWHITE);
    tft.setCursor(20, 140);
    tft.print("Twist | Scream | Tilt");

    if (highScore > 0) {
        char hs[32];
        snprintf(hs, sizeof(hs), "Best: %d", highScore);
        centerText(hs, 180, 2, COL_SCORE);
    }

    centerText("Twist pot to start!", 210, 2, COL_SUCCESS);
}

void showCountdown() {
    for (int i = 3; i >= 1; i--) {
        tft.fillScreen(COL_BG);
        char num[2];
        snprintf(num, sizeof(num), "%d", i);
        centerText(num, 80, 8, COL_TITLE);
        delay(700);
    }
    tft.fillScreen(COL_BG);
    centerText("GO!", 80, 8, COL_SUCCESS);
    delay(500);
}

void showAction(Action a) {
    tft.fillScreen(COL_BG);

    tft.setTextSize(2);
    tft.setTextColor(COL_SCORE);
    tft.setCursor(10, 10);
    tft.printf("Score: %d", score);

    tft.setTextSize(1);
    tft.setTextColor(COL_DIMWHITE);
    tft.setCursor(230, 10);
    tft.printf("Time: %.1fs", timeoutMs / 1000.0f);

    centerText(actionNames[a], 60, 4, COL_ACTION);

    switch (a) {
        case ACT_TWIST:  centerText("Rotate the ear!",      110, 2, COL_DIMWHITE); break;
        case ACT_SCREAM: centerText("Yell at it!",          110, 2, COL_DIMWHITE); break;
        case ACT_CRADLE: centerText("Rock side to side!",   110, 2, COL_DIMWHITE); break;
        default: break;
    }
}

void showSuccess(float reactionMs) {
    tft.fillScreen(COL_BG);
    centerText("NICE!", 40, 5, COL_SUCCESS);

    char buf[32];
    snprintf(buf, sizeof(buf), "%d", score);
    centerText(buf, 100, 6, COL_WHITE);

    snprintf(buf, sizeof(buf), "%.0f ms", reactionMs);
    centerText(buf, 170, 2, COL_SCORE);

    if (reactionMs <= fastestReaction) {
        centerText("NEW BEST!", 200, 2, COL_TITLE);
    }
}

void showGameOver() {
    tft.fillScreen(COL_BG);
    bool won = (score >= WIN_SCORE);

    if (won) {
        centerText("YOU",  15, 5, COL_SUCCESS);
        centerText("WON!", 65, 5, COL_SUCCESS);
    } else {
        centerText("GAME", 15, 5, COL_FAIL);
        centerText("OVER", 65, 5, COL_FAIL);
    }

    char buf[48];
    snprintf(buf, sizeof(buf), "Score: %d", score);
    centerText(buf, 120, 3, COL_WHITE);

    if (score >= highScore) {
        highScore = score;
        centerText("NEW HIGH SCORE!", 155, 2, COL_TITLE);
    } else {
        snprintf(buf, sizeof(buf), "Best: %d", highScore);
        centerText(buf, 155, 2, COL_DIMWHITE);
    }

    tft.setTextSize(1);
    tft.setTextColor(COL_SCORE);

    tft.setCursor(20, 185);
    tft.printf("Twists: %d  Screams: %d  Cradles: %d", twistCount, screamCount, cradleCount);

    if (roundCount > 0) {
        float avgReaction = totalReaction / roundCount;
        tft.setCursor(20, 200);
        tft.printf("Avg reaction: %.0f ms", avgReaction);
        tft.setCursor(20, 215);
        tft.printf("Fastest: %.0f ms", fastestReaction < 99999 ? fastestReaction : 0);
    }

    tft.setCursor(20, 230);
    tft.setTextColor(COL_DIMWHITE);
    tft.print("Twist pot to play again");
}

// ─── Cradle Scene ────────────────────────────────────────────────────────────
void drawCradleScene(float roll, int sidesHit, bool leftLit, bool rightLit,
                     float elapsed, int timeout, bool dirty) {
    const int cx = 160, baseY = 145, armLen = 55;

    if (dirty) {
        tft.fillRect(0, 130, 320, 80, COL_BG);
        tft.drawCircle(40, baseY + armLen, 24, leftLit ? COL_LIT : COL_DIMWHITE);
        tft.drawCircle(40, baseY + armLen, 25, leftLit ? COL_LIT : COL_DIMWHITE);
        tft.drawCircle(280, baseY + armLen, 24, rightLit ? COL_LIT : COL_DIMWHITE);
        tft.drawCircle(280, baseY + armLen, 25, rightLit ? COL_LIT : COL_DIMWHITE);
        tft.fillCircle(cx, baseY, 4, COL_WHITE);
    } else {
        tft.drawCircle(40,  baseY + armLen, 24, leftLit  ? COL_LIT : COL_DIMWHITE);
        tft.drawCircle(40,  baseY + armLen, 25, leftLit  ? COL_LIT : COL_DIMWHITE);
        tft.drawCircle(280, baseY + armLen, 24, rightLit ? COL_LIT : COL_DIMWHITE);
        tft.drawCircle(280, baseY + armLen, 25, rightLit ? COL_LIT : COL_DIMWHITE);
    }

    tft.fillRect(cx - armLen - 12, baseY + 1, (armLen + 12) * 2, armLen + 14, COL_BG);

    float drawRoll = roll;
    if (drawRoll >  90.0f) drawRoll =  90.0f;
    if (drawRoll < -90.0f) drawRoll = -90.0f;

    float rad = drawRoll * (float)DEG_TO_RAD;
    int px = cx + (int)(armLen * sinf(rad));
    int py = baseY + (int)(armLen * cosf(rad));

    tft.drawLine(cx, baseY, px, py, COL_CRADLE);
    tft.drawLine(cx + 1, baseY, px + 1, py, COL_CRADLE);
    tft.fillCircle(px, py, 8, COL_CRADLE);

    float pct = 1.0f - (elapsed / (float)timeout);
    drawProgressBar(10, 220, 300, 12, pct, COL_BAR, COL_BAR_BG);

    char ind[12];
    snprintf(ind, sizeof(ind), "%d/%d", sidesHit, CRADLE_REQUIRED);
    tft.setTextSize(2);
    tft.setTextColor(COL_SCORE);
    tft.fillRect(140, 195, 40, 18, COL_BG);
    tft.setCursor(140, 197);
    tft.print(ind);
}
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
void loop() {
    if (gameRunning) {
        gameLoop();
    } else {
        int baseline = analogRead(PIN_POT);
        while (!gameRunning) {
            int current = analogRead(PIN_POT);
            if (abs(current - baseline) > POT_TWIST_THRESH) {
                startGame();
            }
            delay(50);
        }
    }
}

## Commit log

2026-04-25 Updated: readme and files
    [Knob-designv2.stl, PotInsidePlate_Actobotics_v04.3mf, PotOutsidePlate_Actobotics_v04.STL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]
2026-04-25 Update schematic sheet titles in README.md
2026-04-25 Change project title to 'Bop It — Labubu Edition'
    Updated project title in README.
